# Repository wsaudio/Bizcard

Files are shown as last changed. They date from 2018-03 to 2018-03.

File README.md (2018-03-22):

# Bizcard
Drum machine business card: STM32F030 Based drum machine with 4 sounds and 16 pads

FOLDERS
Hardware:
	- Schematics: PDF of schematics
	- Gerbers: Gerber and drill files required for manufacturer
	- Project Files: KiCad V4.0.0 (or later) required to open
	- BOM: Bill of materials required for manufacture
Software: Created with Keil uVision 5.0

Pins configuration:
PA7: Audio output (TIM1 PWM1)
PA0, PA1, PA2, PA3, PA4: LED/Button MUX Out
PA5, PA6, PA9, PA10: LED MUX In
PA13, PA14, PF0, PF1: Button MUX In

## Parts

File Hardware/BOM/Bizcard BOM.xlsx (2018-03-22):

Reference | Value | Footprint | Notes | Datasheet
C1 | 0.8nF | Capacitors_SMD:C_0402
C2 | 0.1uF | Capacitors_SMD:C_0402
C3 | 0.1uF | Capacitors_SMD:C_0402
C4 | 100uF | Capacitors_SMD:CP_Elec_6.3x4.5 | >= 4V rated
C5 | 0.1uF | Capacitors_SMD:C_0402
D1 | LED_0 | LEDs:LED_0603 | Any 0603 White LED
D10 | LED_6 | LEDs:LED_0603 | Any 0603 White LED
D11 | LED_10 | LEDs:LED_0603 | Any 0603 White LED
D12 | LED_14 | LEDs:LED_0603 | Any 0603 White LED
D13 | LED_3 | LEDs:LED_0603 | Any 0603 White LED
D14 | LED_7 | LEDs:LED_0603 | Any 0603 White LED
D15 | LED_11 | LEDs:LED_0603 | Any 0603 White LED
D16 | LED_15 | LEDs:LED_0603 | Any 0603 White LED
D2 | LED_4 | LEDs:LED_0603 | Any 0603 White LED
D3 | LED_8 | LEDs:LED_0603 | Any 0603 White LED
D4 | LED_12 | LEDs:LED_0603 | Any 0603 White LED
D5 | LED_1 | LEDs:LED_0603 | Any 0603 White LED
D6 | LED_5 | LEDs:LED_0603 | Any 0603 White LED
D7 | LED_9 | LEDs:LED_0603 | Any 0603 White LED
D8 | LED_13 | LEDs:LED_0603 | Any 0603 White LED
D9 | LED_2 | LEDs:LED_0603 | Any 0603 White LED
J1 | JACK_TRS_6PINS | Connectors_USB:Tayda_3.5mm_stereo_TRS_jack_A-853 | Wide style 3.5mm jack
P1 | CONN_01X02 | Pin_Headers:Pin_Header_Straight_1x02_Pitch2.00mm | Not installed - used for programming
P2 | USB_OTG | Connectors_USB:USB_Micro-B_Wuerth-629105150521 | Female micro USB
R1 | 10K | Resistors_SMD:R_0402
R2 | 10K | Resistors_SMD:R_0402
R3 | R | Resistors_SMD:R_0402 | Not installed - used to put in boot mode
R4 | 10K | Resistors_SMD:R_0402
R5 | 10K | Resistors_SMD:R_0402
R6 | 10K | Resistors_SMD:R_0402
R7 | 10K | Resistors_SMD:R_0402
R8 | 10K | Resistors_SMD:R_0402
SW1 | PUSH_0 | Buttons_Switches_ThroughHole:SW_PUSH_6mm | Any 6*6 push button
SW10 | PUSH_6 | Buttons_Switches_ThroughHole:SW_PUSH_6mm | Any 6*6 push button
SW11 | PUSH_10 | Buttons_Switches_ThroughHole:SW_PUSH_6mm | Any 6*6 push button
SW12 | PUSH_14 | Buttons_Switches_ThroughHole:SW_PUSH_6mm | Any 6*6 push button
SW13 | PUSH_3 | Buttons_Switches_ThroughHole:SW_PUSH_6mm | Any 6*6 push button
SW14 | PUSH_7 | Buttons_Switches_ThroughHole:SW_PUSH_6mm | Any 6*6 push button
SW15 | PUSH_11 | Buttons_Switches_ThroughHole:SW_PUSH_6mm | Any 6*6 push button
SW16 | PUSH_15 | Buttons_Switches_ThroughHole:SW_PUSH_6mm | Any 6*6 push button
SW17 | EDIT | Buttons_Switches_ThroughHole:SW_PUSH_6mm | Any 6*6 push button
SW18 | + | Buttons_Switches_ThroughHole:SW_PUSH_6mm | Any 6*6 push button
SW19 | - | Buttons_Switches_ThroughHole:SW_PUSH_6mm | Any 6*6 push button
SW2 | PUSH_4 | Buttons_Switches_ThroughHole:SW_PUSH_6mm | Any 6*6 push button
SW3 | PUSH_8 | Buttons_Switches_ThroughHole:SW_PUSH_6mm | Any 6*6 push button
SW4 | PUSH_12 | Buttons_Switches_ThroughHole:SW_PUSH_6mm | Any 6*6 push button
SW5 | PUSH_1 | Buttons_Switches_ThroughHole:SW_PUSH_6mm | Any 6*6 push button
SW6 | PUSH_5 | Buttons_Switches_ThroughHole:SW_PUSH_6mm | Any 6*6 push button
SW7 | PUSH_9 | Buttons_Switches_ThroughHole:SW_PUSH_6mm | Any 6*6 push button
SW8 | PUSH_13 | Buttons_Switches_ThroughHole:SW_PUSH_6mm | Any 6*6 push button
SW9 | PUSH_2 | Buttons_Switches_ThroughHole:SW_PUSH_6mm | Any 6*6 push button
U1 | STM32F030F4Px | Housings_SSOP:TSSOP-20_4.4x6.5mm_Pitch0.65mm |  | http://www.st.com/content/ccc/resource/technical/document/datasheet/a4/5d/0b/0e/87/c4/4d/71/DM00088500.pdf/files/DM00088500.pdf/jcr:content/translations/en.DM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
U2 | LM358 | Housings_SOIC:SOIC-8_3.9x4.9mm_Pitch1.27mm |  | http://www.st.com/content/ccc/resource/technical/document/datasheet/61/46/87/01/98/ed/44/c5/CD00000464.pdf/files/CD00000464.pdf/jcr:content/translations/en.CD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
U3 | TLV70012DDC | TO_SOT_Packages_SMD:SOT-23-5 |  | http://www.farnell.com/datasheets/2108564.pdf?_ga=2.1061687.70987589.1521559795-54792851.1519643756

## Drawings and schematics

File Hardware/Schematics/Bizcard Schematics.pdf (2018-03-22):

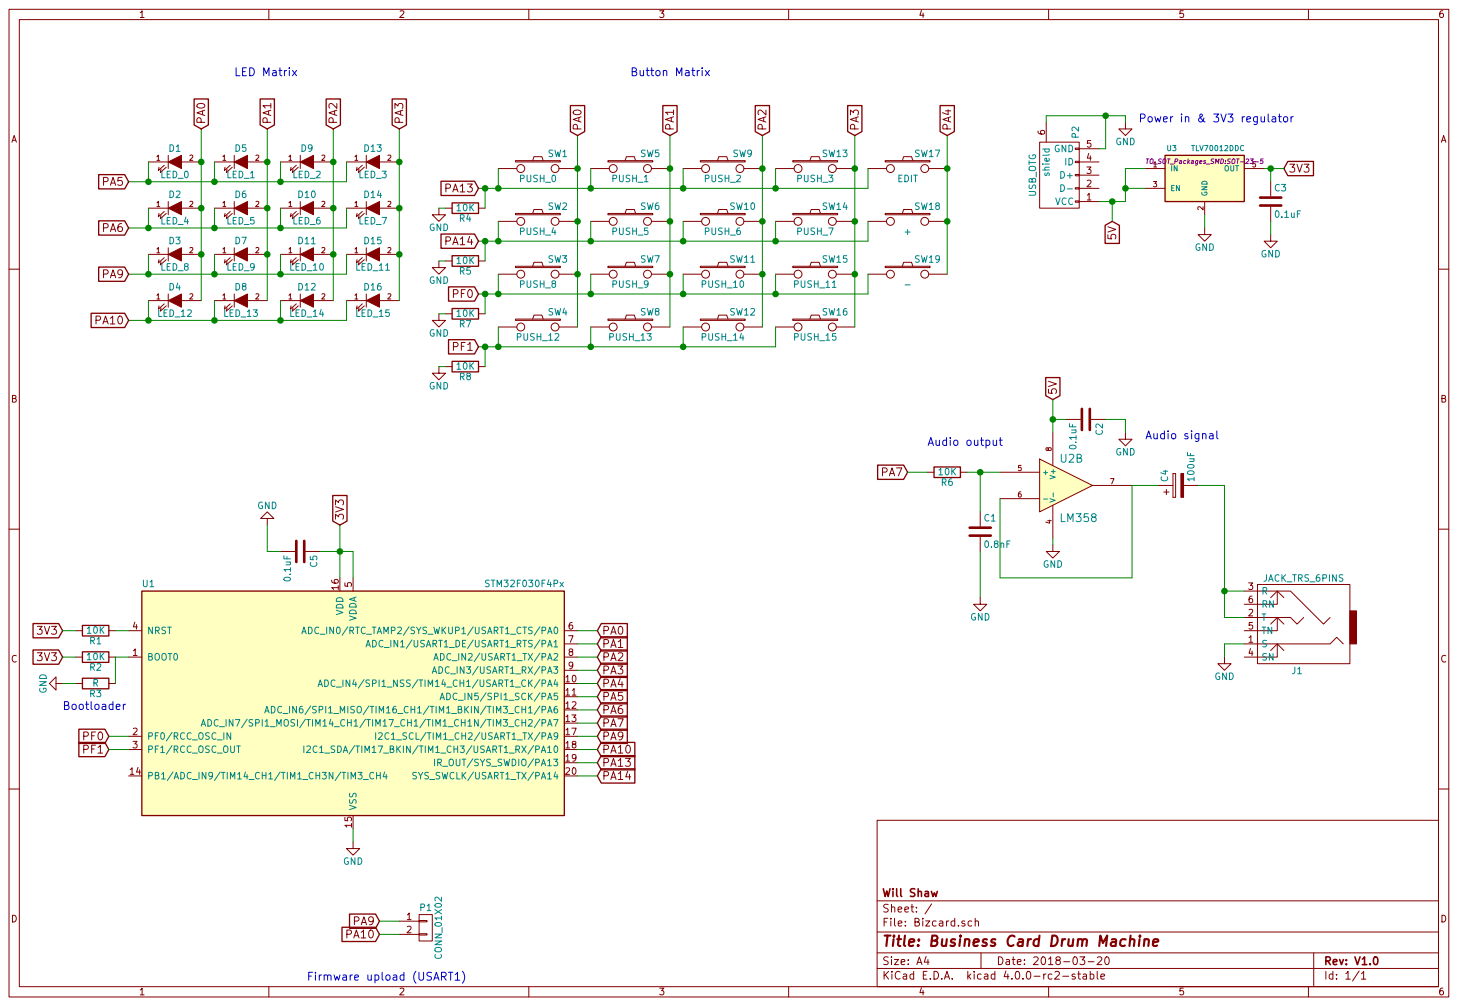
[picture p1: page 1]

10K GND GND GND GND

File: Bizcard.sch Sheet: / Will Shaw

Id: 1/1 Title: Business Card Drum Machine

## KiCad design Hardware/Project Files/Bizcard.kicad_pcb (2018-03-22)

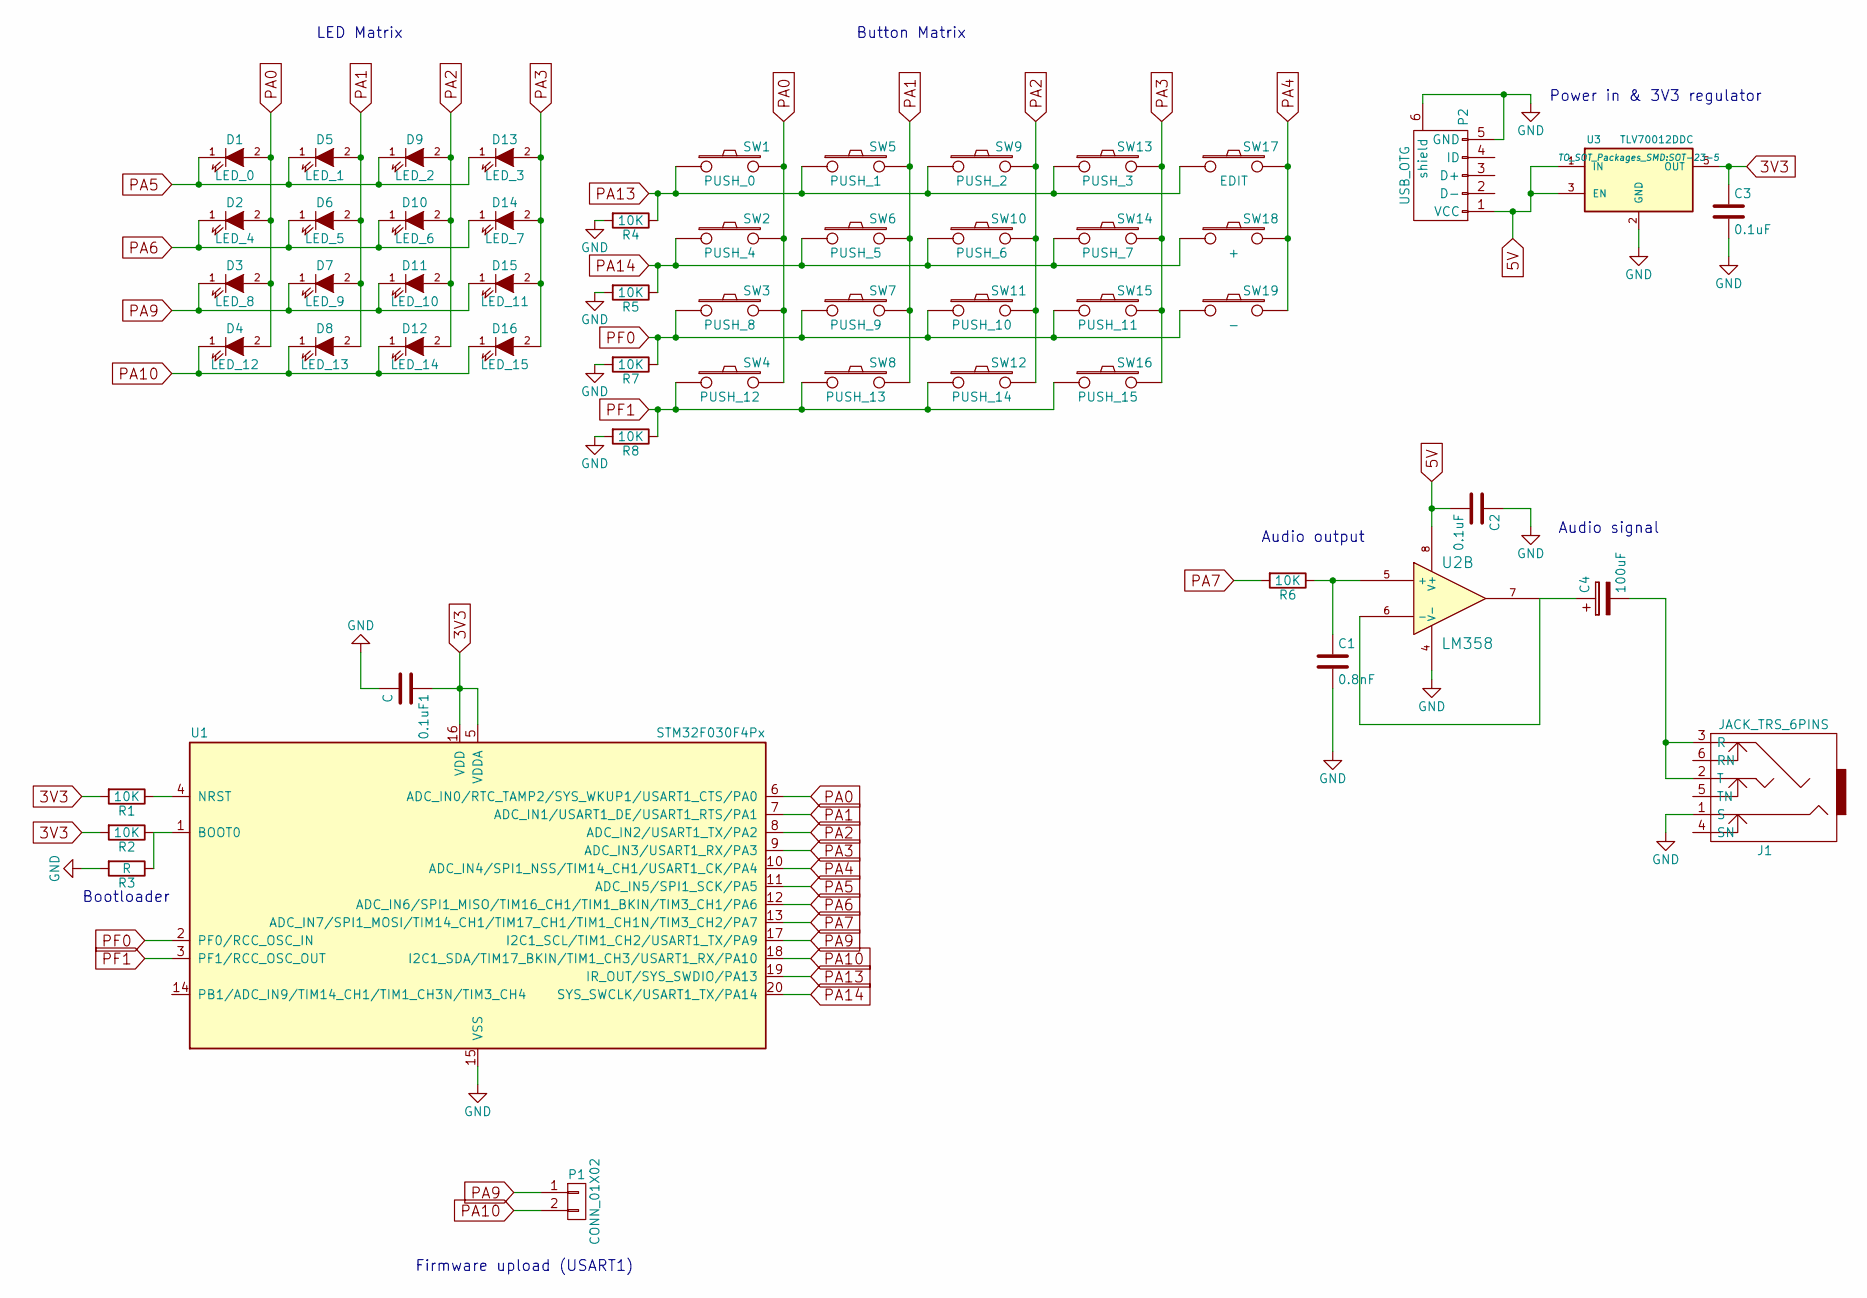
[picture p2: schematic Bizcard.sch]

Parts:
0.1uF1: C; C_0402
C1: 0.8nF; C_0402
C2, C3: 0.1uF; C_0402
C4: 100uF; CP_Elec_6.3x4.5
D1: LED_0; LED_0603
D2: LED_4; LED_0603
D3: LED_8; LED_0603
D4: LED_12; LED_0603
D5: LED_1; LED_0603
D6: LED_5; LED_0603
D7: LED_9; LED_0603
D8: LED_13; LED_0603
D9: LED_2; LED_0603
D10: LED_6; LED_0603
D11: LED_10; LED_0603
D12: LED_14; LED_0603
D13: LED_3; LED_0603
D14: LED_7; LED_0603
D15: LED_11; LED_0603
D16: LED_15; LED_0603
J1: JACK_TRS_6PINS; Tayda_3.5mm_stereo_TRS_jack_A-853
P1: CONN_01X02; Pin_Header_Straight_1x02_Pitch2.00mm
P2: USB_OTG; USB_Micro-B_Wuerth-629105150521
R1, R2, R4, R5, R6, R7, R8: 10K; R_0402
R3: R; R_0402
SW1: PUSH_0; SW_PUSH_6mm
SW2: PUSH_4; SW_PUSH_6mm
SW3: PUSH_8; SW_PUSH_6mm
SW4: PUSH_12; SW_PUSH_6mm
SW5: PUSH_1; SW_PUSH_6mm
SW6: PUSH_5; SW_PUSH_6mm
SW7: PUSH_9; SW_PUSH_6mm
SW8: PUSH_13; SW_PUSH_6mm
SW9: PUSH_2; SW_PUSH_6mm
SW10: PUSH_6; SW_PUSH_6mm
SW11: PUSH_10; SW_PUSH_6mm
SW12: PUSH_14; SW_PUSH_6mm
SW13: PUSH_3; SW_PUSH_6mm
SW14: PUSH_7; SW_PUSH_6mm
SW15: PUSH_11; SW_PUSH_6mm
SW16: PUSH_15; SW_PUSH_6mm
SW17: EDIT; SW_PUSH_6mm
SW18: +; SW_PUSH_6mm
SW19: -; SW_PUSH_6mm
U1: STM32F030F4Px; TSSOP-20_4.4x6.5mm_Pitch0.65mm
U2: LM358; SOIC-8_3.9x4.9mm_Pitch1.27mm
U3: TLV70012DDC; SOT-23-5

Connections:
3V3: 0.1uF1.1, C3.1, R1.2, R2.2, U1.5 (VDDA), U1.16 (VDD), U3.5 (OUT)
5V: C2.2, P2.1 (VCC), U2.8 (V+), U3.1 (IN), U3.3 (EN)
GND: 0.1uF1.2, C1.2, C2.1, C3.2, J1.1 (S), P2.5 (GND), P2.6 (shield), R3.2, R4.2, R5.2, R7.2, R8.2, U1.15 (VSS), U2.4 (V-), U3.2 (GND)
unnamed: C1.1, R6.1, U2.5 (+)
unnamed: C4.1, U2.6 (-), U2.7
unnamed: C4.2, J1.2 (T), J1.3 (R)
unnamed: R1.1, U1.4 (NRST)
unnamed: R2.1, R3.1, U1.1 (BOOT0)
PA0: D1.2 (A), D2.2 (A), D3.2 (A), D4.2 (A), SW1.2, SW2.2, SW3.2, SW4.2, U1.6 (ADC_IN0/RTC_TAMP2/SYS_WKUP1/USART1_CTS/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)
PA1: D5.2 (A), D6.2 (A), D7.2 (A), D8.2 (A), SW5.2, SW6.2, SW7.2, SW8.2, U1.7 (ADC_IN1/USART1_DE/USART1_RTS/PA1)
PA2: D9.2 (A), D10.2 (A), D11.2 (A), D12.2 (A), SW9.2, SW10.2, SW11.2, SW12.2, U1.8 (ADC_IN2/USART1_TX/PA2)
PA3: D13.2 (A), D14.2 (A), D15.2 (A), D16.2 (A), SW13.2, SW14.2, SW15.2, SW16.2, U1.9 (ADC_IN3/USART1_RX/PA3)
PA4: SW17.2, SW18.2, SW19.2, U1.10 (ADC_IN4/SPI1_NSS/TIM14_CH1/USART1_CK/PA4)
PA5: D1.1 (K), D5.1 (K), D9.1 (K), D13.1 (K), U1.11 (ADC_IN5/SPI1_SCK/PA5)
PA6: D2.1 (K), D6.1 (K), D10.1 (K), D14.1 (K), U1.12 (ADC_IN6/SPI1_MISO/TIM16_CH1/TIM1_BKIN/T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)
PA7: R6.2, U1.13 (ADC_IN7/SPI1_MOSI/TIM14_CH1/TIM17_CH1/T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)
PA9: D3.1 (K), D7.1 (K), D11.1 (K), D15.1 (K), P1.1, U1.17 (I2C1_SCL/TIM1_CH2/USART1_TX/PA9)
PA10: D4.1 (K), D8.1 (K), D12.1 (K), D16.1 (K), P1.2, U1.18 (I2C1_SDA/TIM17_BKIN/TIM1_CH3/USART1_RX/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)
PA13: R4.1, SW1.1, SW5.1, SW9.1, SW13.1, SW17.1, U1.19 (IR_OUT/SYS_SWDIO/PA13)
PA14: R5.1, SW2.1, SW6.1, SW10.1, SW14.1, SW18.1, U1.20 (SYS_SWCLK/USART1_TX/PA14)
PF0: R7.1, SW3.1, SW7.1, SW11.1, SW15.1, SW19.1, U1.2 (PF0/RCC_OSC_IN)
PF1: R8.1, SW4.1, SW8.1, SW12.1, SW16.1, U1.3 (PF1/RCC_OSC_OUT)

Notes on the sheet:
Firmware upload (USART1)
LED Matrix
Button Matrix
Power in & 3V3 regulator
Audio output
Audio signal
Bootloader

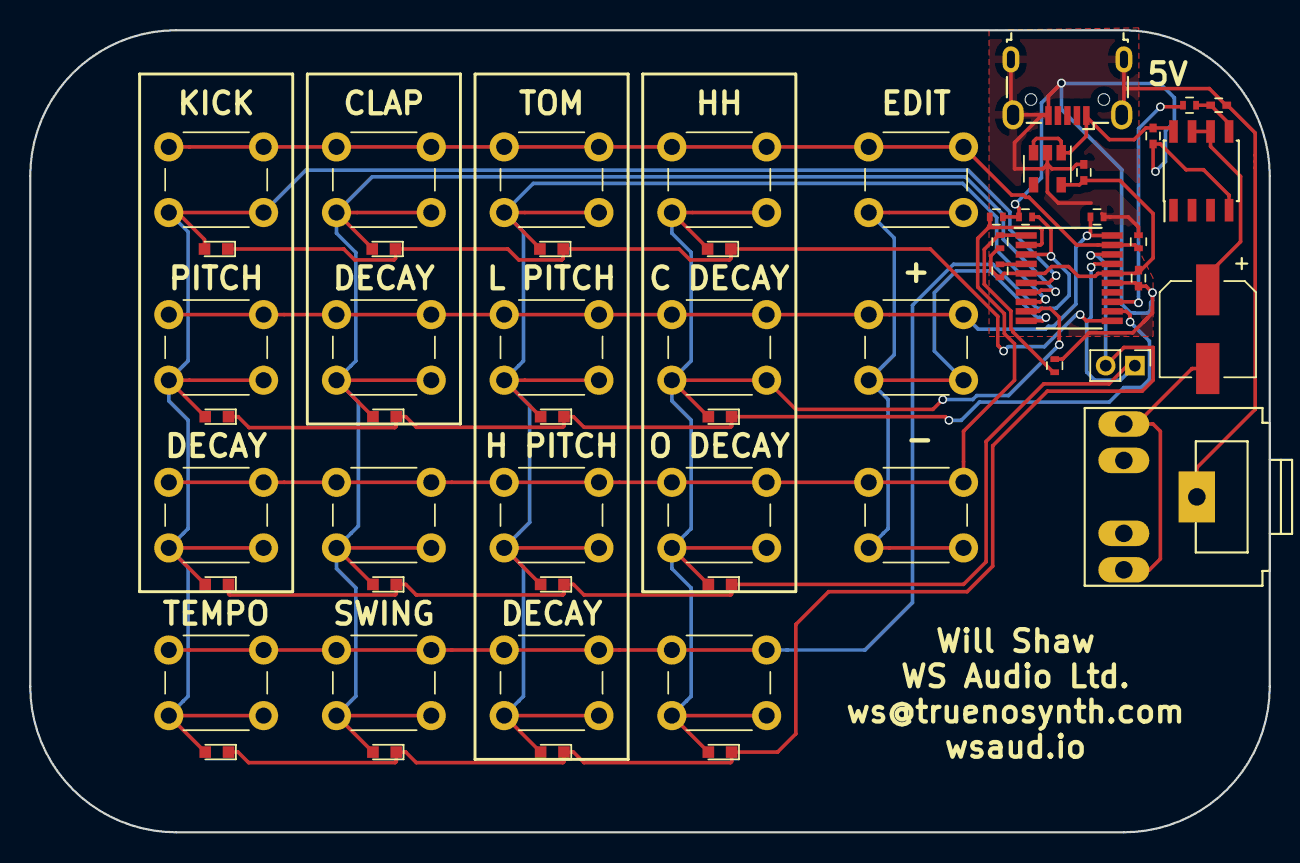
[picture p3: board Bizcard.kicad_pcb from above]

Board: 2 copper layers, 85.0 x 55.0 mm, 54 parts (0 on the bottom side), 22 nets.

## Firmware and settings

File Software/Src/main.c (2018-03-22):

/* Includes ------------------------------------------------------------------*/
#include "stm32f0xx_hal.h"
#include "Kick.h"
#include "Tom.h"
#include "Sequencer.h"
#include "Master Audio.h"

/* Defines -------------------------------------------------------------------*/
#define tim1Period 1024	- 1		//8 bit PWM audio output (46.875kHz - 2x oversampling)
#define tim3Period 48000 - 1	//LED/Button multiplexing interrupt (1kHz)

/* Private variables ---------------------------------------------------------*/
TIM_HandleTypeDef htim1;
TIM_HandleTypeDef htim3;
TIM_HandleTypeDef htim14;

/* Private function prototypes -----------------------------------------------*/
void SystemClock_Config(void);
static void MX_GPIO_Init(void);
static void MX_TIM_Init(void);
static void startTimers(void);
static void initParameters(void);

int main(void)
{
  //Reset of all peripherals, Initializes the Flash interface and the Systick.
  HAL_Init();

  //Configure the system clock
  SystemClock_Config();

  //Initialise all configured peripherals
  MX_GPIO_Init();
  MX_TIM_Init();
	
	//Initialise voices and sequencer
	initParameters();
	
	//Start timers and interrupts
	startTimers();
		
	startAudioPlayback();

  while (1)
  {
  }
}

/** System Clock Configuration
*/
void SystemClock_Config(void)
{
  RCC_OscInitTypeDef RCC_OscInitStruct;
  RCC_ClkInitTypeDef RCC_ClkInitStruct;

  RCC_OscInitStruct.OscillatorType = RCC_OSCILLATORTYPE_HSI;
  RCC_OscInitStruct.HSIState = RCC_HSI_ON;
  RCC_OscInitStruct.HSICalibrationValue = 16;
  RCC_OscInitStruct.PLL.PLLState = RCC_PLL_ON;
  RCC_OscInitStruct.PLL.PLLSource = RCC_PLLSOURCE_HSI;
  RCC_OscInitStruct.PLL.PLLMUL = RCC_PLL_MUL12;
  RCC_OscInitStruct.PLL.PREDIV = RCC_PREDIV_DIV1;
  HAL_RCC_OscConfig(&RCC_OscInitStruct);

  RCC_ClkInitStruct.ClockType = RCC_CLOCKTYPE_SYSCLK;
  RCC_ClkInitStruct.SYSCLKSource = RCC_SYSCLKSOURCE_PLLCLK;
  RCC_ClkInitStruct.AHBCLKDivider = RCC_SYSCLK_DIV1;
  RCC_ClkInitStruct.APB1CLKDivider = RCC_HCLK_DIV1;
  HAL_RCC_ClockConfig(&RCC_ClkInitStruct, FLASH_LATENCY_1);

  //HAL_SYSTICK_Config(systickPeriod);

  //HAL_SYSTICK_CLKSourceConfig(SYSTICK_CLKSOURCE_HCLK);
	
	//Disable systick
	SysTick->CTRL  = 0;
}

/* TIM1 init function */
void MX_TIM_Init(void)
{
	GPIO_InitTypeDef GPIO_InitStruct;
  TIM_MasterConfigTypeDef sMasterConfig;
  TIM_BreakDeadTimeConfigTypeDef sBreakDeadTimeConfig;
  TIM_OC_InitTypeDef sConfigOC;
	
	__HAL_RCC_TIM1_CLK_ENABLE();
	__HAL_RCC_TIM14_CLK_ENABLE();
	
	GPIO_InitStruct.Pin = GPIO_PIN_7;
	GPIO_InitStruct.Mode = GPIO_MODE_AF_PP;
	GPIO_InitStruct.Pull = GPIO_NOPULL;
	GPIO_InitStruct.Speed = GPIO_SPEED_LOW;
	GPIO_InitStruct.Alternate = GPIO_AF4_TIM14;
	HAL_GPIO_Init(GPIOA, &GPIO_InitStruct);

	HAL_NVIC_SetPriority(TIM14_IRQn, 0, 0);
	HAL_NVIC_EnableIRQ(TIM14_IRQn);

  htim14.Instance = TIM14;
  htim14.Init.Prescaler = 0;
  htim14.Init.CounterMode = TIM_COUNTERMODE_UP;
  htim14.Init.Period = tim1Period;
  htim14.Init.ClockDivision = TIM_CLOCKDIVISION_DIV1;
  htim14.Init.RepetitionCounter = 0;
  HAL_TIM_PWM_Init(&htim14);
	
	HAL_NVIC_SetPriority(TIM1_BRK_UP_TRG_COM_IRQn, 1, 0);
	HAL_NVIC_EnableIRQ(TIM1_BRK_UP_TRG_COM_IRQn);
	htim1.Instance = TIM1;
	htim1.Init.Period = tim1Period;
	htim1.Init.Prescaler = 512 - 1;
	HAL_TIM_Base_Init(&htim1);

  sMasterConfig.MasterOutputTrigger = TIM_TRGO_RESET;
  sMasterConfig.MasterSlaveMode = TIM_MASTERSLAVEMODE_DISABLE;
  HAL_TIMEx_MasterConfigSynchronization(&htim14, &sMasterConfig);

  sBreakDeadTimeConfig.OffStateRunMode = TIM_OSSR_DISABLE;
  sBreakDeadTimeConfig.OffStateIDLEMode = TIM_OSSI_DISABLE;
  sBreakDeadTimeConfig.LockLevel = TIM_LOCKLEVEL_OFF;
  sBreakDeadTimeConfig.DeadTime = 0;
  sBreakDeadTimeConfig.BreakState = TIM_BREAK_DISABLE;
  sBreakDeadTimeConfig.BreakPolarity = TIM_BREAKPOLARITY_HIGH;
  sBreakDeadTimeConfig.AutomaticOutput = TIM_AUTOMATICOUTPUT_DISABLE;
  HAL_TIMEx_ConfigBreakDeadTime(&htim14, &sBreakDeadTimeConfig);

  sConfigOC.OCMode = TIM_OCMODE_PWM1;
  sConfigOC.Pulse = 0;
  sConfigOC.OCPolarity = TIM_OCPOLARITY_HIGH;
  sConfigOC.OCNPolarity = TIM_OCNPOLARITY_HIGH;
  sConfigOC.OCFastMode = TIM_OCFAST_DISABLE;
  sConfigOC.OCIdleState = TIM_OCIDLESTATE_RESET;
  sConfigOC.OCNIdleState = TIM_OCNIDLESTATE_RESET;
	
  HAL_TIM_PWM_ConfigChannel(&htim14, &sConfigOC, TIM_CHANNEL_1);
	HAL_TIM_PWM_Start(&htim14, TIM_CHANNEL_1);
	HAL_TIM_Base_Start_IT(&htim14);
	
	TIM_ClockConfigTypeDef sClockSourceConfig;

  htim3.Instance = TIM3;
  htim3.Init.Prescaler = 0;
  htim3.Init.CounterMode = TIM_COUNTERMODE_UP;
  htim3.Init.Period = tim3Period;
  htim3.Init.ClockDivision = TIM_CLOCKDIVISION_DIV1;
  HAL_TIM_Base_Init(&htim3);

  sClockSourceConfig.ClockSource = TIM_CLOCKSOURCE_INTERNAL;
  HAL_TIM_ConfigClockSource(&htim3, &sClockSourceConfig);

  sMasterConfig.MasterOutputTrigger = TIM_TRGO_RESET;
  sMasterConfig.MasterSlaveMode = TIM_MASTERSLAVEMODE_DISABLE;
  HAL_TIMEx_MasterConfigSynchronization(&htim3, &sMasterConfig);
}

/** Configure pins as 
        * Analog 
        * Input 
        * Output
        * EVENT_OUT
        * EXTI
*/
void MX_GPIO_Init(void)
{
  GPIO_InitTypeDef GPIO_InitStruct;

  /* GPIO Ports Clock Enable */
  __GPIOF_CLK_ENABLE();
  __GPIOA_CLK_ENABLE();

  /*Configure GPIO pins : PF0 PF1 */
  GPIO_InitStruct.Pin = GPIO_PIN_0|GPIO_PIN_1;
  GPIO_InitStruct.Mode = GPIO_MODE_INPUT;
  GPIO_InitStruct.Pull = GPIO_NOPULL;
  HAL_GPIO_Init(GPIOF, &GPIO_InitStruct);

  /*Configure GPIO pins : PA0 PA1 PA2 PA3 
                           PA4 PA5 PA6 PA9 
                           PA10 */
  GPIO_InitStruct.Pin = GPIO_PIN_0|GPIO_PIN_1|GPIO_PIN_2|GPIO_PIN_3 
                          |GPIO_PIN_4|GPIO_PIN_5|GPIO_PIN_6|GPIO_PIN_9 
                          |GPIO_PIN_10;
  GPIO_InitStruct.Mode = GPIO_MODE_OUTPUT_PP;
  GPIO_InitStruct.Pull = GPIO_NOPULL;
  GPIO_InitStruct.Speed = GPIO_SPEED_LOW;
  HAL_GPIO_Init(GPIOA, &GPIO_InitStruct);

  /*Configure GPIO pins : PA13 PA14 */
  GPIO_InitStruct.Pin = GPIO_PIN_13|GPIO_PIN_14;
  GPIO_InitStruct.Mode = GPIO_MODE_INPUT;
  GPIO_InitStruct.Pull = GPIO_NOPULL;
  //HAL_GPIO_Init(GPIOA, &GPIO_InitStruct);
}

static void startTimers(void)
{
	HAL_TIM_Base_Start_IT(&htim1);
	HAL_TIM_Base_Start_IT(&htim3);
	HAL_TIM_Base_Start_IT(&htim14);
	HAL_TIM_PWM_Start(&htim1, TIM_CHANNEL_1);
}

static void initParameters(void)
{
	initSequencerParams();
	initKickParams();
	initClapParams();
	initHHParams();
	initTomParams();
	initAudio();
	
}

#ifdef USE_FULL_ASSERT

/**
   * @brief Reports the name of the source file and the source line number
   * where the assert_param error has occurred.
   * @param file: pointer to the source file name
   * @param line: assert_param error line source number
   * @retval None
   */
void assert_failed(uint8_t* file, uint32_t line)
{
}

#endif

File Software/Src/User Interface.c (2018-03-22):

#include "User Interface.h"

uint8_t currentMenu = 0; //Currently selected menu item (0 - 14)
uint8_t currentSequence = 0; //Current instrument being displayed & edited (0 - 5)
uint8_t editButtonPressed = 0;
uint8_t buttonStatus[2][noOfButtonRowDrivers][noOfUIColumnDrivers]; //Stores current and previous button status

uint8_t currentUIMuxColumn = 0; //Current LED & button column being driven & checked

//GPIO pin allocations
const uint16_t UIColumnGPIONo[noOfUIColumnDrivers] = { GPIO_PIN_0, GPIO_PIN_1, GPIO_PIN_2, GPIO_PIN_3, GPIO_PIN_4 };
const uint16_t LEDRowGPIONo[noOfLEDRowDrivers] = { GPIO_PIN_5, GPIO_PIN_6, GPIO_PIN_9, GPIO_PIN_10 };
const uint16_t ButtonRowGPIONo[noOfLEDRowDrivers] = { GPIO_PIN_13, GPIO_PIN_14, GPIO_PIN_0, GPIO_PIN_1 };
GPIO_TypeDef* ButtonRowGPIOBank[noOfLEDRowDrivers] = { GPIOA, GPIOA, GPIOF, GPIOF };

/*uiMuxInterrupt
Main LED & button multiplex loop
*/
void uiMuxInterrupt(void)
{
	switchUIColumnDrivers();
	switchCurrentLEDColumn();
	checkCurrentButtonColumn();
	incrementMuxElement();
}

/*switchUIColumnDrivers
Switch LED & button multiplex driver columns
*/
void switchUIColumnDrivers(void)
{
	//Check range
	if (currentUIMuxColumn < noOfUIColumnDrivers)
	{
		for (uint8_t i = 0; i < noOfUIColumnDrivers; i++)
		{
			//Off
			if (i != currentUIMuxColumn)
				HAL_GPIO_WritePin(GPIOA, UIColumnGPIONo[i], GPIO_PIN_RESET);
			
			//On
			else
				HAL_GPIO_WritePin(GPIOA, UIColumnGPIONo[i], GPIO_PIN_SET);
		}
	}
}

/*switchCurrentLEDColumn
Switch on or off LEDs in current driver column
*/
void switchCurrentLEDColumn()
{
	uint8_t currentLEDStatus; 
	
	for (uint8_t i = 0; i < noOfLEDRowDrivers; i++)
	{
		currentLEDStatus = getCurrentLEDStatus(i, currentUIMuxColumn);
		
		//Off
		if (currentLEDStatus == 0)
			HAL_GPIO_WritePin(GPIOA, LEDRowGPIONo[i], GPIO_PIN_SET);
		
		//On
		else
			HAL_GPIO_WritePin(GPIOA, LEDRowGPIONo[i], GPIO_PIN_RESET);
	}
}

/*checkCurrentButtonColumn
Check button status in current driver column
*/
void checkCurrentButtonColumn(void)
{
	uint8_t currentButtonStatus;
	
	updateButtonPressHistory();
	
	for (uint8_t i = 0; i < noOfLEDRowDrivers; i++)
	{
		currentButtonStatus = HAL_GPIO_ReadPin(ButtonRowGPIOBank[i], ButtonRowGPIONo[i]);
		buttonStatus[currentStatus][i][currentUIMuxColumn] = currentButtonStatus;
	}
}

/*incrementMuxElement
Increment current multiplex driver column and process button inputs
*/
void incrementMuxElement(void)
{
	//Increment LED/button column
	currentUIMuxColumn++;
	
	//At end of columns
	if (currentUIMuxColumn >= noOfUIColumnDrivers)
	{
		currentUIMuxColumn -= noOfUIColumnDrivers;
		processPressedButtons();
	}
}

/*updateButtonPressHistory
Move current button data to previous data
*/
void updateButtonPressHistory(void)
{
	for (uint8_t i = 0; i < noOfButtonRowDrivers; i++)
	{
		for (int8_t j = 0; j < noOfUIColumnDrivers; j++)
		{
			buttonStatus[prevStatus][i][j] = buttonStatus[currentStatus][i][j];
		}
	}
}

/*processPressedButtons
Process buttons pressed since last loop
*/
void processPressedButtons(void)
{
	//If edit button is pressed
	if (buttonStatus[currentStatus][editButtonY][editButtonX])
		switchCurrentMenu();
	
	//Value + button
	else if (checkForNewPress(incButtonY, incButtonX))
		changeValue(1);
	
	//Value - button
	else if (checkForNewPress(decButtonY, decButtonX))
		changeValue(0);
	
	//Check remaining buttons
	else
		processPads();
}

/*switchCurrentMenu
Switch the current parameter being controlled by the + or - buttons.
Also switches currently displayed sequence
*/
void switchCurrentMenu(void)
{
	editButtonPressed = 1; 
	
	for (uint8_t i = 0; i < noOfButtonRowDrivers; i++)
	{
		for (int8_t j = 0; j < 4; j++)
		{
			if (buttonStatus[i][j])
			{
				//Change current menu
				currentMenu = i * noOfButtonRowDrivers + j;
				
				//change current sequence
				if ((checkForNewPress(i, j)) && (i == 0))
					switchCurrentSequence(j);
				
				goto out;
			}
		}
	}
	
	out:;
}

/*switchCurrentSequence
Change the currently displayed sequence
buttonNo: button pressed
*/
void switchCurrentSequence(uint8_t buttonNo)
{
	//Check range
	if (buttonNo < 4)
	{
		switch (buttonNo)
		{
			//Kick
			case 0:
				currentSequence = 0;
				break;
			
			//Clap
			case 1:
				currentSequence = 1;
				break;
			
			//Low/high tom
			case 2:
				if (currentSequence == 2)
					currentSequence = 3;
				else
					currentSequence = 2;
				break;
			
			//Close/open HH
			case 3:
				if (currentSequence == 4)
					currentSequence = 5;
				else
					currentSequence = 4;
				break;
		}
	}
}

/*processPads
Process currently pressed drum pads and send to sequencer
*/
void processPads(void)
{
	uint8_t stepNo;
	
	for (uint8_t i = 0; i < noOfButtonRowDrivers; i++)
	{
		for (int8_t j = 0; j < 4; j++)
		{
			if (checkForNewPress(i, j))
			{
				stepNo = i * noOfButtonRowDrivers + j;
				addOrRemoveSequencerStep(currentSequence, stepNo);
			}
		}
	}
}

/*changeValue
Increase or decrease value of currently selected parameter
newVal: 0 = decrease, 1 = increase
*/
void changeValue(uint8_t newVal)
{
	//Check range
	if (newVal < 2)
	{
		switch (currentMenu)
		{
			//Kick volume
			case 0:
				setGeneratorVol(kickNo, newVal);
				break;
			
			//Clap volume
			case 1:
				setGeneratorVol(clapNo, newVal);
				break;
			
			//Tom volume
			case 2:
				setGeneratorVol(tomNo, newVal);
				break;
			
			//HH volume
			case 3:
				setGeneratorVol(hhNo, newVal);
				break;
			
			//Kick pitch
			case 4:
				changeKickPitch(newVal);
				break;
			
			//Clap decay
			case 5:
				changeClapDecayTime(newVal);
				break;
			
			//Low tom pitch
			case 6:
				changeTomPitch(0, newVal);
				break;
			
			//HH close decay
			case 7:
				changeHHDecayTime(0, newVal);
				break;
			
			//Kick decay
			case 8:
				changeKickDecayTime(newVal);
				break;
			
			//High tom pitch
			case 10:
				changeTomPitch(1, newVal);
				break;
			
			//HH open decay
			case 11:
				changeHHDecayTime(1, newVal);
				break;
			
			//Sequencer swing
			case 12:
				changeSequencerSwing(newVal);
				break;
			
			//Sequencer tempo
			case 13:
				changeSequencerTempo(newVal);
				break;
			
			//Tom decay
			case 14:
				changeTomDecayTime(newVal);
				break;
			
			default:
				break;
		}
	}
}
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
